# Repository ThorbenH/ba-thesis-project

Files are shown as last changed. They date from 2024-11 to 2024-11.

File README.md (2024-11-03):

# BarbelMotionTracker

This git project is dedicated to a prototype implementation that attempts to track and evaluate the motion of a barbell in the gym.

## 3D-Files

Here you will find the FFF (FDM) printable files for a case for the board. All STL-files are in metric (mm). To complete the assembly you will need some additional hardware (M3 screws, rubber pad, M3 heat set inserts, 4mmx0.5mm brass tubing, 2cm wide velcro strap)

## PCB_Design

Here you will find the KiCad8.0 design files as well as the pre exported gerbers (ready to order at JLCPCB). You will also find the ibom.html file which is a Interactive Bill Of Materials that you can open in any modern browser. It is of great use when doing board smd assembly.

## Software_Device

Here you will find a PlatformIO project that contains the software running on the board. It is written in C/C++ for the esp32 platform using the arduino framework.

To get started install VSCode, install the PlatformIO extension, plug in the board using the USB-C shared power and data port and make sure the board is turned on using the power switch.p

The software collects all the raw sensor data into a CSV-File for future of board processing.

Calibration modes can be selected by uncommenting preprocessor arguments in the "platformio.ini" file.

### Micro SD-Card

The sd-card has to be formatted as FAT32. FAT32 is only supported by micro-sd-cards with capacity less than 32GB.
The sd-card has to contain a settings.txt file that has to be populated. Check the "sdcard.h" code for details.
A good starting point might be this (make sure to include the empty lines at the end of the file, as the device expects these to write the BNO055 calibration to):

```
User
1
s
90.00
2.50
45.00
2.50
12.50
2.50
95.00
2.50

```

## Plot_Calibration

Contains a the python code to visualize a calibration as gathered by the device (see Software_Device).
To get the calibration matrix you can use the tool Magneto v1.2 at https://sites.google.com/view/sailboatinstruments1 .

## Post_Process_Data

First run "apply_calibration_and_split.py" to split one recording session into exercises and sets and apply the calibration. This requires a recorded session and a "cal_matrix.json" file in the subfolder "data". Make sure to set the correct file name for your recordig in "apply_calibration_and_split.py".
Next you can run "compute_orientation_and_motion.py". Make sure to set the correct target folder.

Some settings are required for these two steps. They can be set in "processing_settings.py".

All other files should contain "_thesis" in their name and where only used to create plots of the data for the thesis. Feel free to disregard these.

## Machine_Learning
To run the machine learning code you first need to create the dataset used for training and testing. The python code file "prepData.py" uses a hard coded location for the data. To generate the data required first run the Post_Process_Data pipeline. Then you can run the training in order "prepData.py" -> "train.py" -> "test.py".

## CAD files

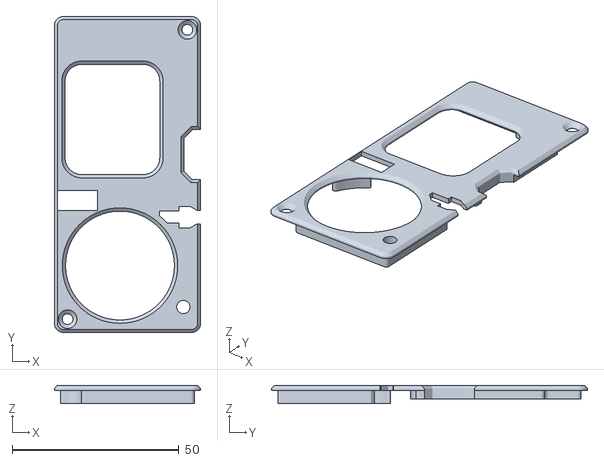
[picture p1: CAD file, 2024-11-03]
3D-Files/Lid.stl
43.9 x 94.7 x 5.40

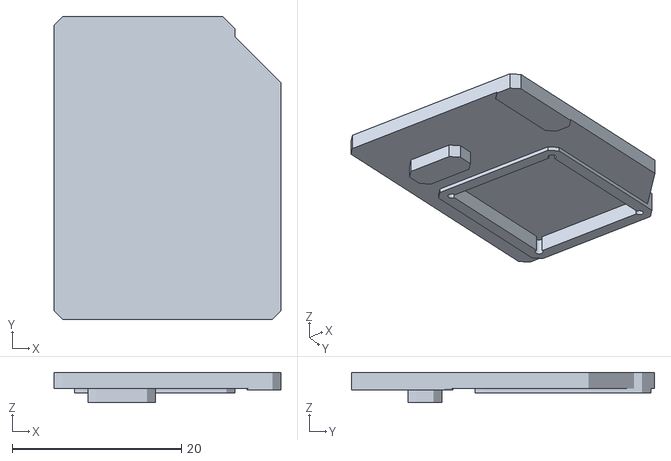
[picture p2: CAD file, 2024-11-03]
3D-Files/ScreenBackSupport.stl
26.8 x 35.8 x 3.55

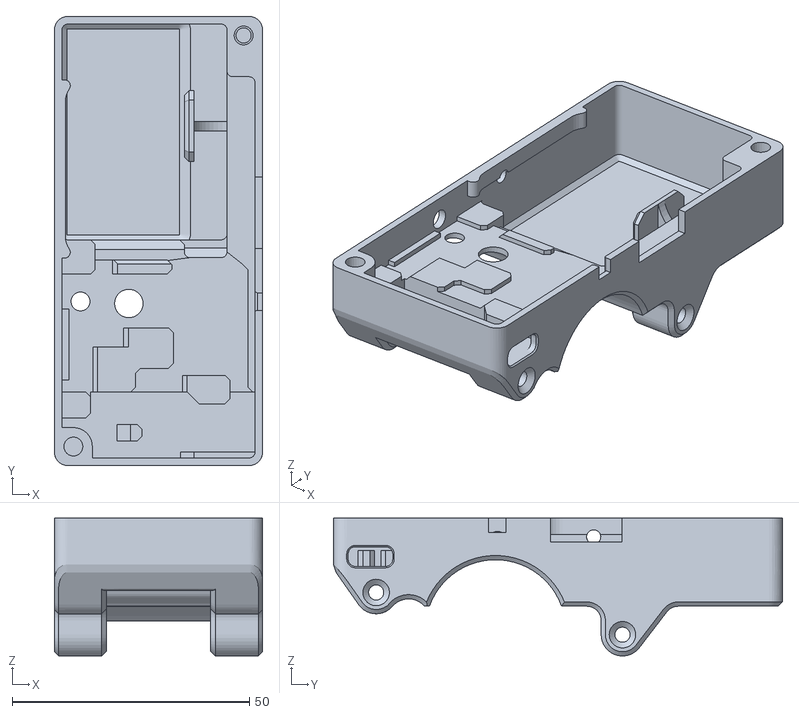
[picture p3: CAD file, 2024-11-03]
3D-Files/Case.stl
43.9 x 94.7 x 29.1

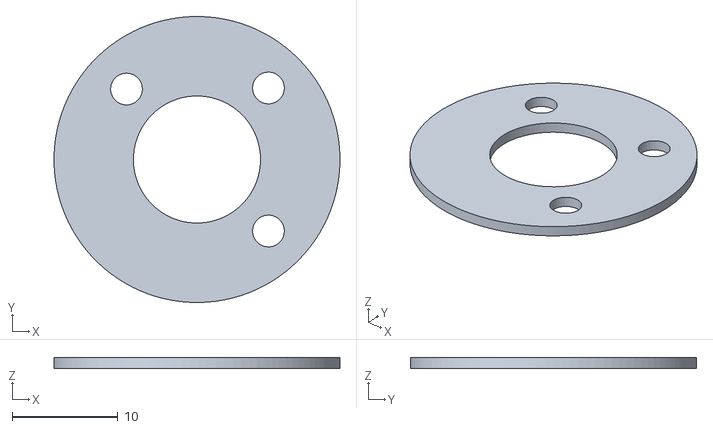
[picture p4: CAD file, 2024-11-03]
3D-Files/EncoderSpacer.stl
27.0 x 27.0 x 1.00

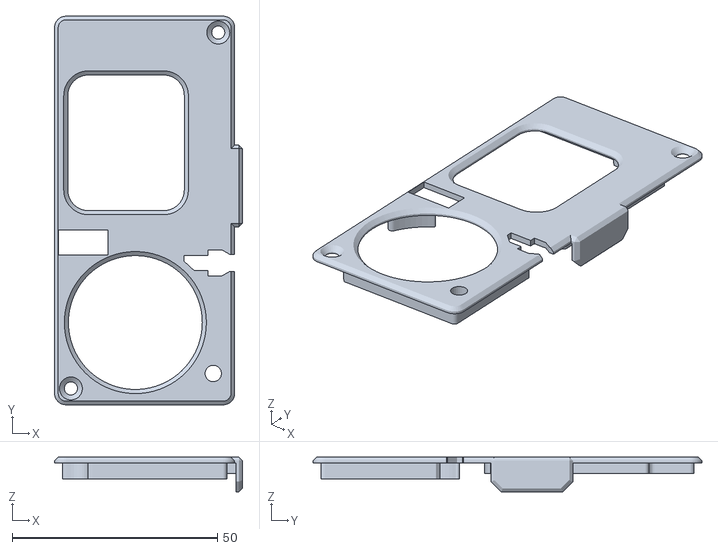
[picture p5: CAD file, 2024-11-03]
3D-Files/LidClosedSD.stl
45.8 x 94.7 x 8.50

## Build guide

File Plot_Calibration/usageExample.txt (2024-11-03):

18.92700	34.72900	-2.31934	
19.04907	34.93652	-1.98975	
19.01245	34.74731	-2.24609	
18.95142	34.85107	-1.94092	
19.01245	34.98535	-1.89209	
19.01245	34.98535	-1.89209	
19.13452	34.91211	-2.33154	
18.93921	34.80225	-2.27051	
19.05518	34.85107	-2.13623	
18.97583	34.91821	-2.27661	
18.97583	34.91821	-2.27661	
19.00024	34.84497	-2.34375	
19.06738	34.73511	-2.32544	
19.06738	34.73511	-2.32544	
18.90869	34.82056	-2.19727	
18.87817	35.02197	-2.22168	
18.91479	34.96094	-2.07520	
18.91479	34.96094	-2.07520	
19.01245	35.02808	-2.13013	
18.87817	34.80225	-2.25220	
18.90869	34.93042	-2.14844	
18.99414	35.05859	-2.15454	
18.99414	35.05859	-2.15454	
18.86597	35.19287	-2.17285	
19.00635	35.04028	-2.03247	
19.00635	35.04028	-2.03247	
19.14062	35.11963	-2.08740	
18.93311	35.09521	-2.27051	
19.03687	35.02197	-1.98975	
18.90869	35.09521	-1.98975	
18.90869	35.09521	-1.98975	
18.84155	35.29053	-1.64795	
19.02466	35.24170	-2.05688	
19.02466	35.24170	-2.05688	
19.17114	35.27222	-1.96533	
19.33594	35.32104	-1.97754	
19.17725	35.24780	-1.89819	
19.17114	35.24170	-1.90430	
19.17114	35.24170	-1.90430	
19.25659	35.51636	-2.06299	
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

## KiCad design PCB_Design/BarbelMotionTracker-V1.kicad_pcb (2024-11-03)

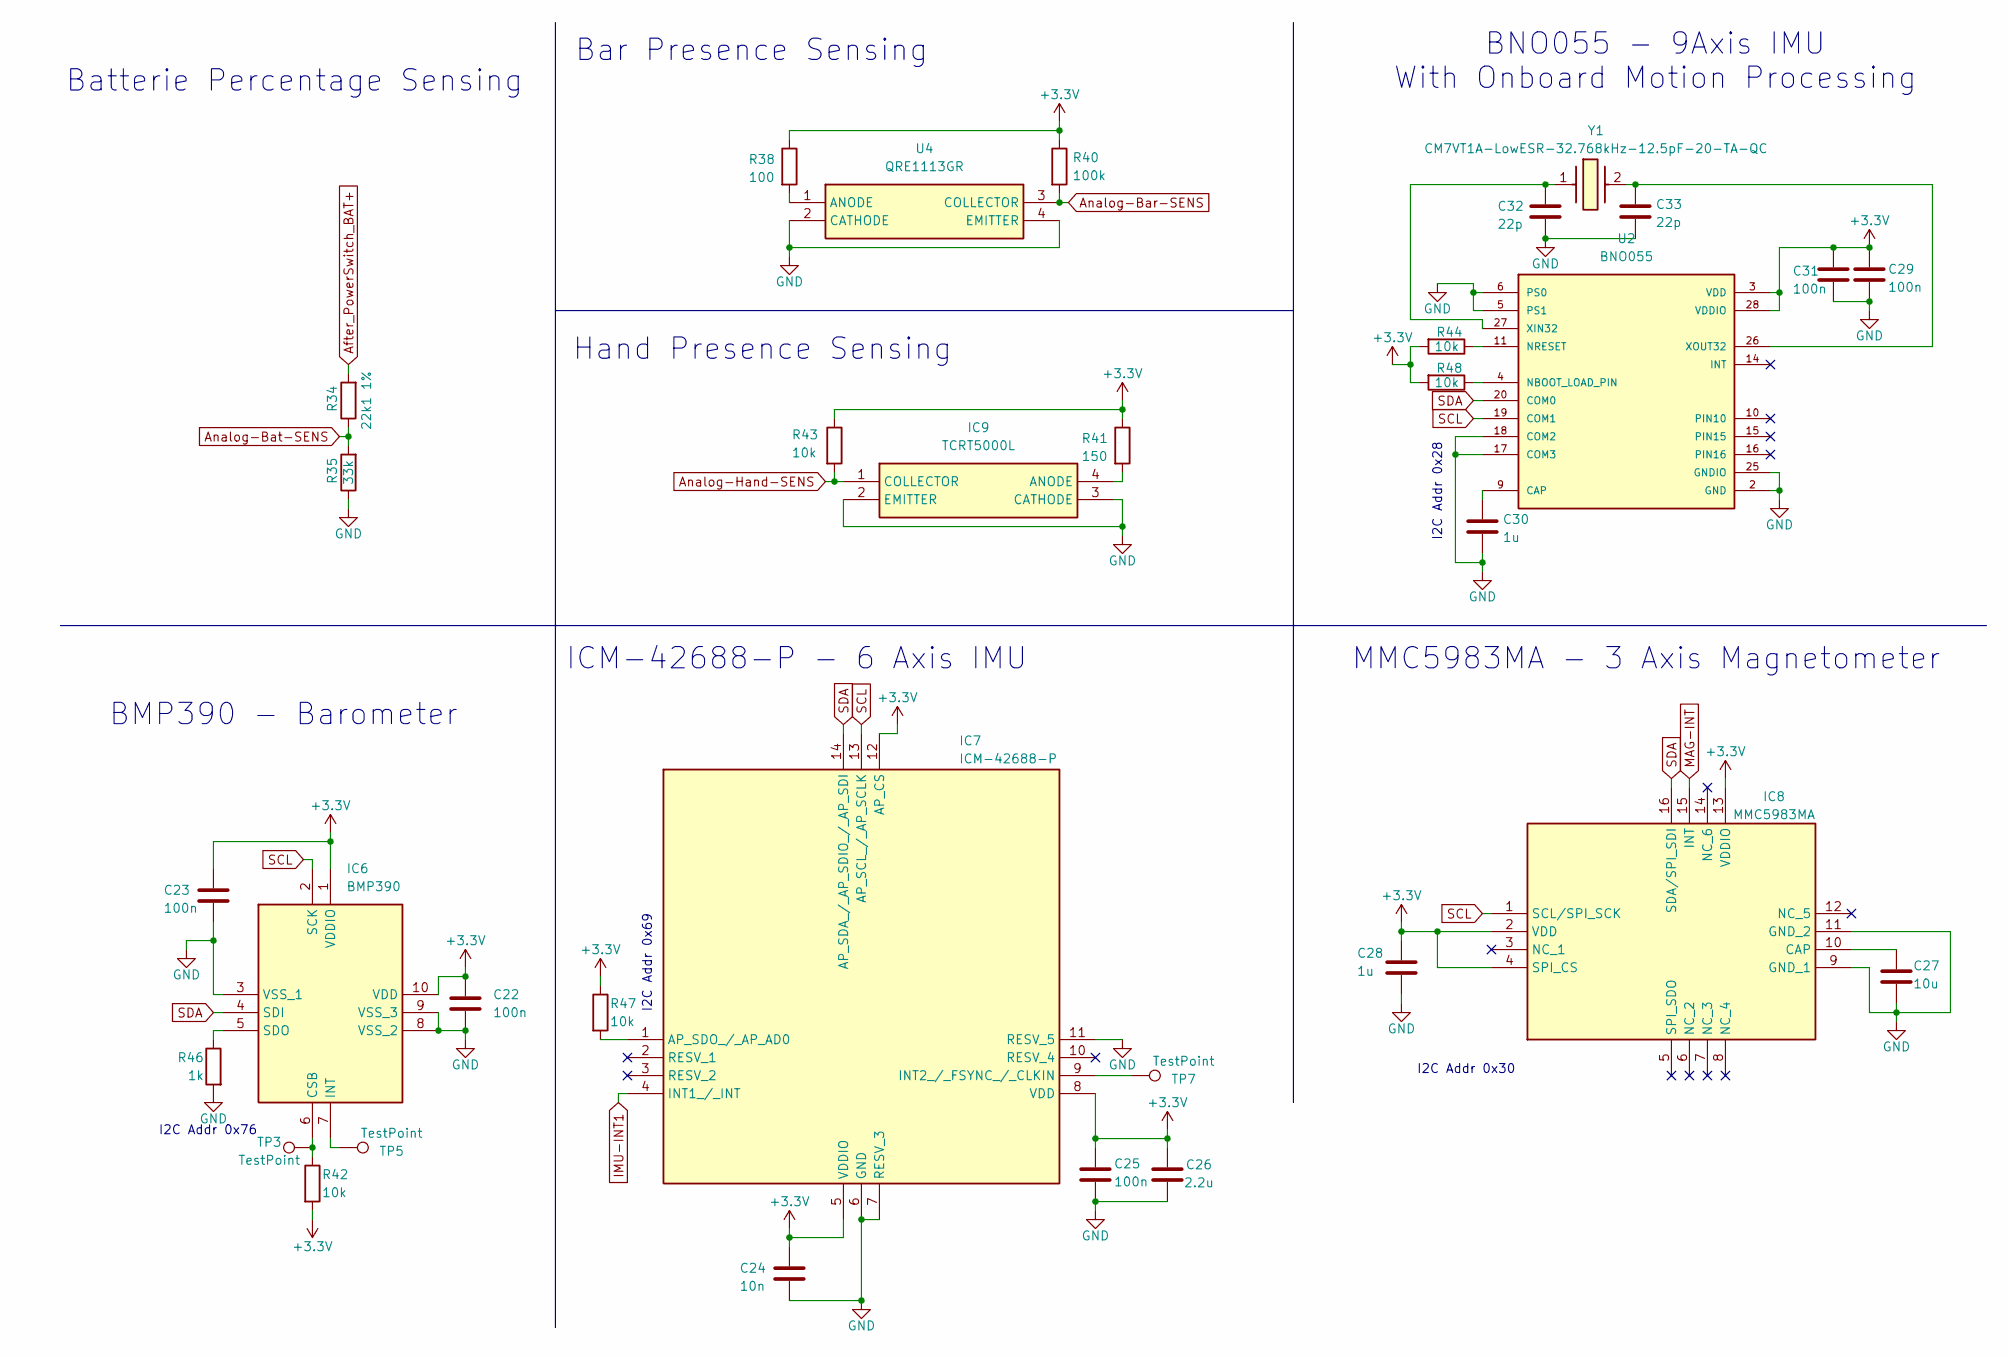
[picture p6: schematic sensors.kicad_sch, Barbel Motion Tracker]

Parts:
C22, C23, C25, C29, C31: 100n; C_0603_1608Metric
C24: 10n; C_0603_1608Metric
C26: 2.2u; C_0603_1608Metric
C27: 10u; C_0805_2012Metric
C28, C30: 1u; C_0603_1608Metric
C32, C33: 22p; C_0402_1005Metric
IC6: BMP390; Mouser Part Number 262-BMP390
IC7: ICM-42688-P; IIM42352; Mouser Part Number 410-ICM-42688-P
IC8: MMC5983MA; Mouser Part Number 438-MMC5983MA
IC9: TCRT5000L; Mouser Part Number 782-TCRT5000L
R34: 22k1 1%; R_0603_1608Metric
R35: 33k; R_0603_1608Metric
R38: 100; R_1206_3216Metric
R40: 100k; R_0603_1608Metric
R41: 150; R_1206_3216Metric
R42, R43, R44, R47, R48: 10k; R_0603_1608Metric
R46: 1k; R_0603_1608Metric
TP3, TP5, TP7: TestPoint; TestPoint_Pad_D1.0mm
U2: BNO055; LGA28R50P4X10_380X520X100
U4: QRE1113GR; Mouser Part Number 512-QRE1113GR
Y1: CM7VT1A-LowESR-32.768kHz-12.5pF-20-TA-QC; CM7V32768TBQA020; Mouser Part Number 428-202740-MG01

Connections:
+3.3V: C22.1, C23.1, C24.1, C25.1, C26.1, C28.1, C29.1, C31.1, IC6.1 (VDDIO), IC6.10 (VDD), IC7.5 (VDDIO), IC7.8 (VDD), IC7.12 (AP_CS), IC8.2 (VDD), IC8.4 (SPI_CS), IC8.13 (VDDIO), R38.1, R40.1, R41.1, R42.2, R43.1, R44.2, R47.1, R48.2, U2.3 (VDD), U2.28 (VDDIO); also elsewhere on the board
After_PowerSwitch_BAT+: R34.2; also elsewhere on the board
Analog-Bar-SENS: R40.2, U4.3 (COLLECTOR); also elsewhere on the board
Analog-Bat-SENS: R34.1, R35.2; also elsewhere on the board
Analog-Hand-SENS: IC9.1 (COLLECTOR), R43.2; also elsewhere on the board
GND: C22.2, C23.2, C24.2, C25.2, C26.2, C27.2, C28.2, C29.2, C30.2, C31.2, C32.2, C33.2, IC6.3 (VSS_1), IC6.8 (VSS_2), IC6.9 (VSS_3), IC7.6 (GND), IC7.7 (RESV_3), IC7.11 (RESV_5), IC8.9 (GND_1), IC8.11 (GND_2), IC9.2 (EMITTER), IC9.3 (CATHODE), R35.1, R46.2, U2.2 (GND), U2.5 (PS1), U2.6 (PS0), U2.17 (COM3), U2.18 (COM2), U2.25 (GNDIO), U4.2 (CATHODE), U4.4 (EMITTER); also elsewhere on the board
IMU-INT1: IC7.4 (INT1_/_INT); also elsewhere on the board
MAG-INT: IC8.15 (INT); also elsewhere on the board
unnamed: IC6.6 (CSB), R42.1, TP3.1
unnamed: IC6.7 (INT), TP5.1
unnamed: IC6.5 (SDO), R46.1
unnamed: IC7.1 (AP_SDO_/_AP_AD0), R47.2
unnamed: IC7.9 (INT2_/_FSYNC_/_CLKIN), TP7.1
unnamed: C27.1, IC8.10 (CAP)
unnamed: IC9.4 (ANODE), R41.2
unnamed: C30.1, U2.9 (CAP)
unnamed: R48.1, U2.4 (NBOOT_LOAD_PIN)
unnamed: R44.1, U2.11 (NRESET)
unnamed: C32.1, U2.27 (XIN32), Y1.1
unnamed: C33.1, U2.26 (XOUT32), Y1.2
unnamed: R38.2, U4.1 (ANODE)
SCL: IC6.2 (SCK), IC7.13 (AP_SCL_/_AP_SCLK), IC8.1 (SCL/SPI_SCK), U2.19 (COM1); also elsewhere on the board
SDA: IC6.4 (SDI), IC7.14 (AP_SDA_/_AP_SDIO_/_AP_SDI), IC8.16 (SDA/SPI_SDI), U2.20 (COM0); also elsewhere on the board

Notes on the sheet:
BMP390 - Barometer
I2C Addr 0x28
Batterie Percentage Sensing
ICM-42688-P - 6 Axis IMU
BNO055 - 9Axis IMU With Onboard Motion Processing
MMC5983MA - 3 Axis Magnetometer
Hand Presence Sensing
I2C Addr 0x69
I2C Addr 0x76
Bar Presence Sensing
I2C Addr 0x30

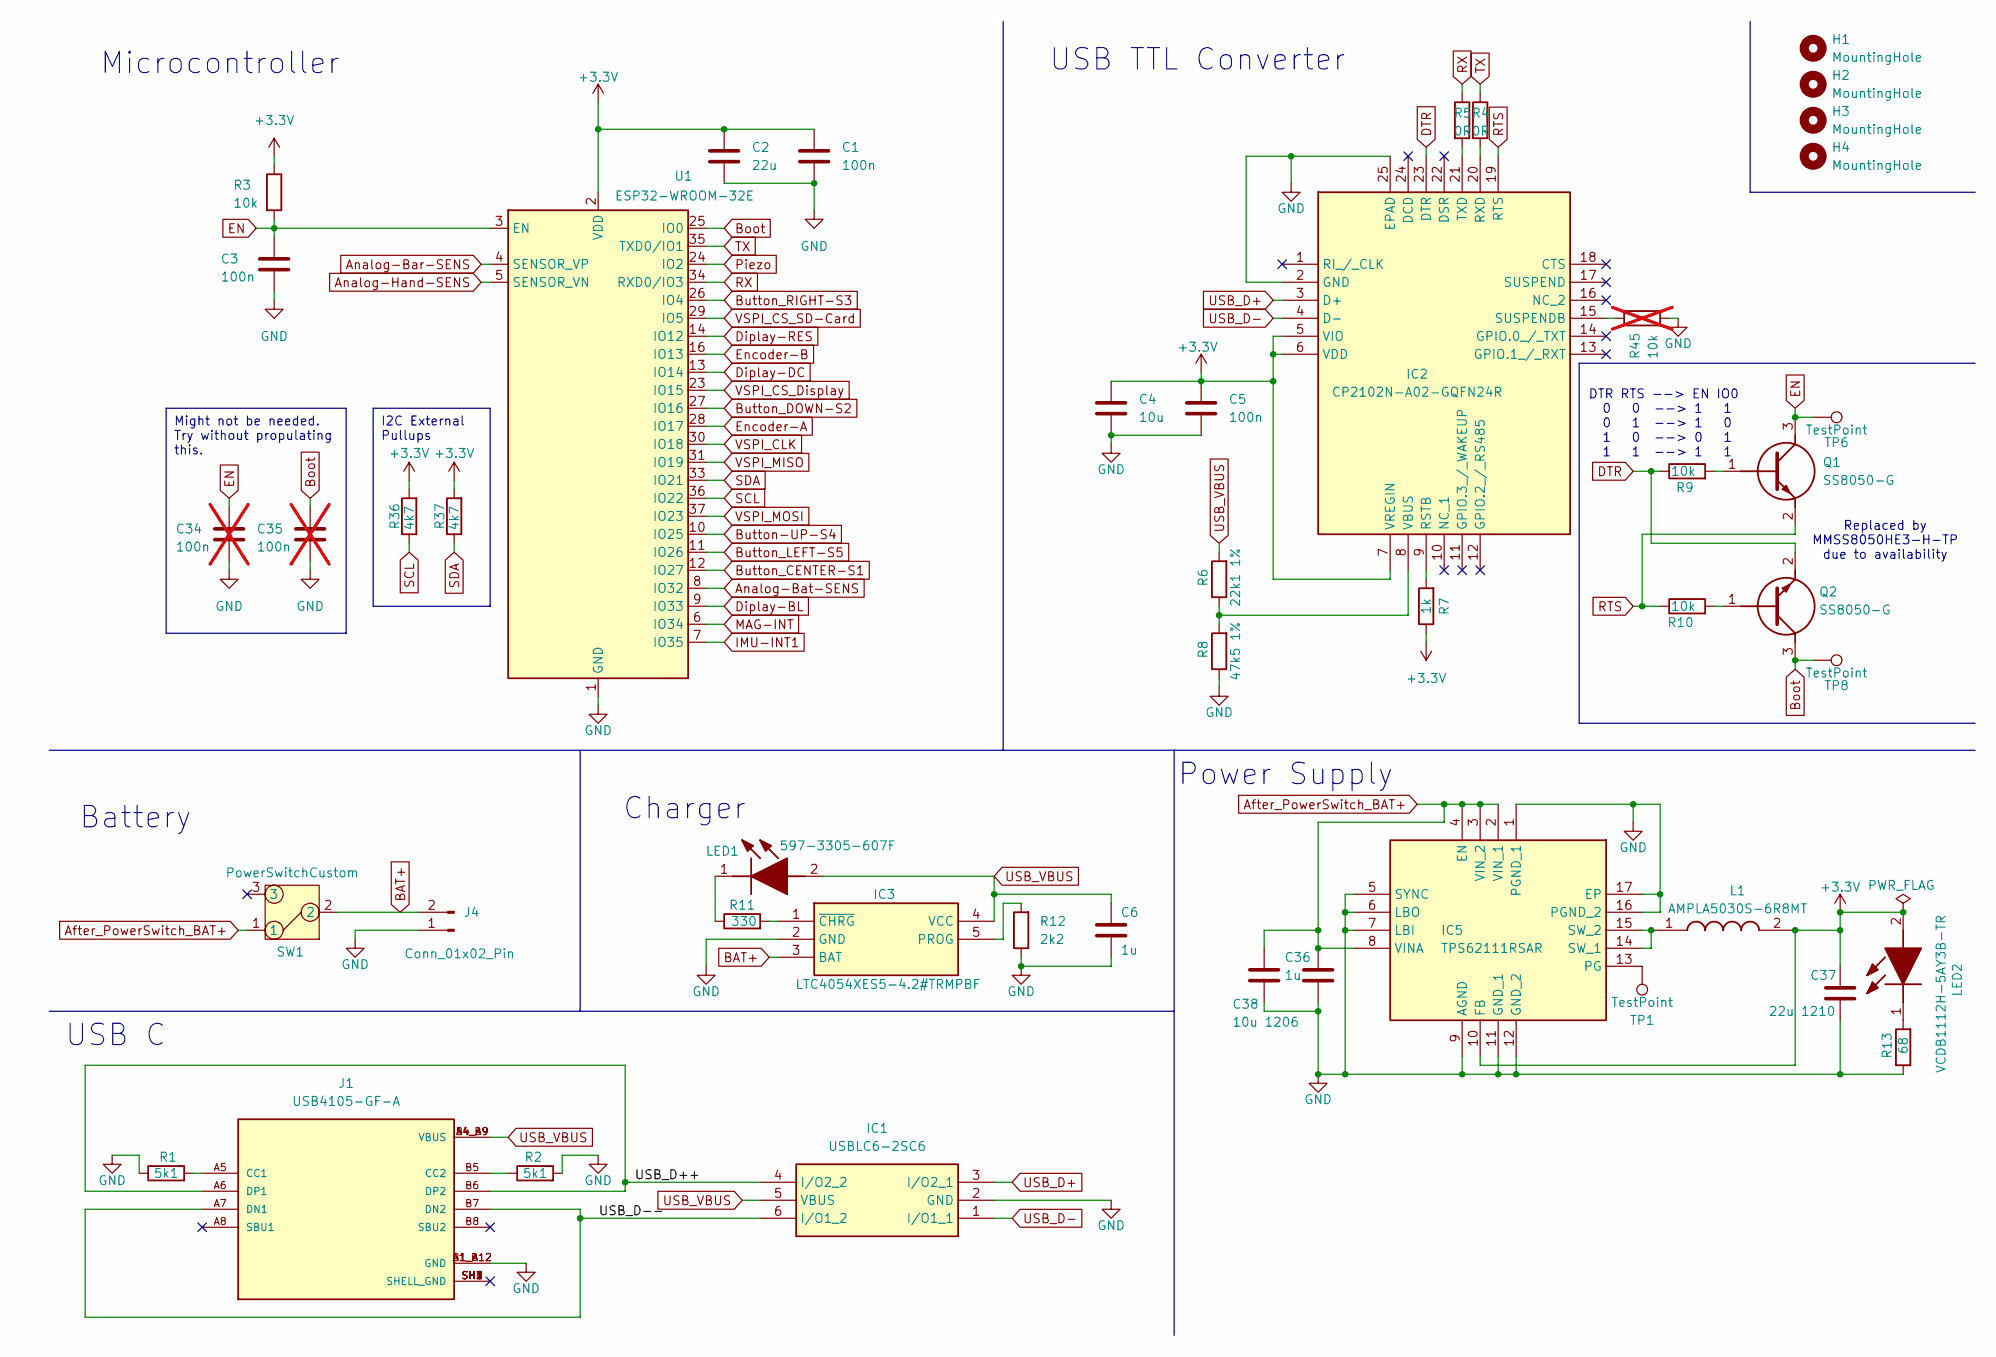
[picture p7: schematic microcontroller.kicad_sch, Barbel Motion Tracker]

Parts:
C1, C3, C5: 100n; C_0603_1608Metric
C2: 22u; C_0805_2012Metric
C4: 10u; C_0805_2012Metric
C6, C36: 1u; C_0603_1608Metric
C34, C35: 100n; C_0603_1608Metric; not fitted
C37: 22u 1210; C_1210_3225Metric
C38: 10u 1206; C_1206_3216Metric
H1, H2, H3, H4: MountingHole; MountingHole_2.2mm_M2
IC1: USBLC6-2SC6; SOT95P280X145-6N; Mouser Part Number 511-USBLC6-2SC6
IC2: CP2102N-A02-GQFN24R; QFN50P400X400X80-25N-D; Mouser Part Number 634-CP2102NA02QFN24R
IC3: LTC4054XES5-4.2#TRMPBF; SOT95P280X100-5N; Mouser Part Number 584-C4054XES54.2TMPF
IC5: TPS62111RSAR; QFN65P400X400X100-17N; Mouser Part Number 595-TPS62111RSAR
J1: USB4105-GF-A; GCT_USB4105-GF-A; PARTREV B3
J4: Conn_01x02_Pin; JST_PH_S2B-PH-K_1x02_P2.00mm_Horizontal
L1: AMPLA5030S-6R8MT; INDPM5752X300N; Manufacturer_Part_Number AMPLA5030S-6R8MT
LED1: 597-3305-607F; LEDC2012X70N; Mouser Part Number 645-597-3305-607F
LED2: VCDB1112H-5AY3B-TR; LEDC2012X90N; Mouser Part Number 327-VCDB1112H5AY3BTR
Q1, Q2: SS8050-G; SOT95P240X115-3N; Mouser Part Number 750-SS8050-G
R1, R2: 5k1; R_0603_1608Metric
R3, R9, R10: 10k; R_0603_1608Metric
R4, R5: 0R; R_0603_1608Metric
R6: 22k1 1%; R_0603_1608Metric
R7: 1k; R_0603_1608Metric
R8: 47k5 1%; R_0603_1608Metric
R11: 330; R_0603_1608Metric
R12: 2k2; R_0603_1608Metric
R13: 68; R_0603_1608Metric
R36, R37: 4k7; R_0603_1608Metric
R45: 10k; R_0603_1608Metric; not fitted
SW1: PowerSwitchCustom
TP1, TP6, TP8: TestPoint; TestPoint_Pad_D1.0mm
U1: ESP32-WROOM-32E

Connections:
+3.3V: C1.1, C2.1, C4.1, C5.1, C37.1, IC2.5 (VIO), IC2.6 (VDD), IC2.7 (VREGIN), IC5.10 (FB), L1.2, LED2.2 (A), R3.1, R7.1, R36.2, R37.2, U1.2 (VDD); also elsewhere on the board
/microcontroller/USB_D++: IC1.4 (I/O2_2), J1.A6 (DP1), J1.B6 (DP2)
/microcontroller/USB_D--: IC1.6 (I/O1_2), J1.A7 (DN1), J1.B7 (DN2)
After_PowerSwitch_BAT+: C36.1, C38.1, IC5.2 (VIN_1), IC5.3 (VIN_2), IC5.4 (EN), IC5.8 (VINA), SW1.1; also elsewhere on the board
Analog-Bar-SENS: U1.4 (SENSOR_VP); also elsewhere on the board
Analog-Bat-SENS: U1.8 (IO32); also elsewhere on the board
Analog-Hand-SENS: U1.5 (SENSOR_VN); also elsewhere on the board
BAT+: IC3.3 (BAT), J4.2, SW1.2
Boot: C35.1, Q2.3 (C), TP8.1, U1.25 (IO0)
Button-UP-S4: U1.10 (IO25); also elsewhere on the board
Button_CENTER-S1: U1.12 (IO27); also elsewhere on the board
Button_DOWN-S2: U1.27 (IO16); also elsewhere on the board
Button_LEFT-S5: U1.11 (IO26); also elsewhere on the board
Button_RIGHT-S3: U1.26 (IO4); also elsewhere on the board
DTR: IC2.23 (DTR), Q2.2 (E), R9.1
Diplay-BL: U1.9 (IO33); also elsewhere on the board
Diplay-DC: U1.13 (IO14); also elsewhere on the board
Diplay-RES: U1.14 (IO12); also elsewhere on the board
EN: C3.1, C34.1, Q1.3 (C), R3.2, TP6.1, U1.3 (EN)
Encoder-A: U1.28 (IO17); also elsewhere on the board
Encoder-B: U1.16 (IO13); also elsewhere on the board
GND: C1.2, C2.2, C3.2, C4.2, C5.2, C6.2, C34.2, C35.2, C36.2, C37.2, C38.2, IC1.2 (GND), IC2.2 (GND), IC2.25 (EPAD), IC3.2 (GND), IC5.1 (PGND_1), IC5.5 (SYNC), IC5.6 (LBO), IC5.7 (LBI), IC5.9 (AGND), IC5.11 (GND_1), IC5.12 (GND_2), IC5.16 (PGND_2), IC5.17 (EP), J1.A1_B12 (GND), J1.B1_A12 (GND), J4.1, R1.1, R2.2, R8.1, R12.1, R13.1, R45.2, U1.1 (GND), U1.15 (GND), U1.38 (GND), U1.39 (GND); also elsewhere on the board
IMU-INT1: U1.7 (IO35); also elsewhere on the board
MAG-INT: U1.6 (IO34); also elsewhere on the board
unnamed: IC2.9 (RSTB), R7.2
unnamed: IC2.20 (RXD), R4.2
unnamed: IC2.15 (SUSPENDB), R45.1
unnamed: IC2.21 (TXD), R5.2
unnamed: IC2.8 (VBUS), R6.1, R8.2
unnamed: IC3.5 (PROG), R12.2
unnamed: IC3.1 (~CHRG), R11.2
unnamed: IC5.13 (PG), TP1.1
unnamed: IC5.14 (SW_1), IC5.15 (SW_2), L1.1
unnamed: J1.A5 (CC1), R1.2
unnamed: J1.B5 (CC2), R2.1
unnamed: LED1.1 (K), R11.1
unnamed: LED2.1 (K), R13.2
unnamed: Q1.1 (B), R9.2
unnamed: Q2.1 (B), R10.2
Piezo: U1.24 (IO2); also elsewhere on the board
RTS: IC2.19 (RTS), Q1.2 (E), R10.1
RX: R5.1, U1.34 (RXD0/IO3)
SCL: R36.1, U1.36 (IO22); also elsewhere on the board
SDA: R37.1, U1.33 (IO21); also elsewhere on the board
TX: R4.1, U1.35 (TXD0/IO1)
USB_D+: IC1.3 (I/O2_1), IC2.3 (D+)
USB_D-: IC1.1 (I/O1_1), IC2.4 (D-)
USB_VBUS: C6.1, IC1.5 (VBUS), IC3.4 (VCC), J1.A4_B9 (VBUS), J1.B4_A9 (VBUS), LED1.2 (A), R6.2
VSPI_CLK: U1.30 (IO18); also elsewhere on the board
VSPI_CS_Display: U1.23 (IO15); also elsewhere on the board
VSPI_CS_SD-Card: U1.29 (IO5); also elsewhere on the board
VSPI_MISO: U1.31 (IO19); also elsewhere on the board
VSPI_MOSI: U1.37 (IO23); also elsewhere on the board

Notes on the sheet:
I2C External Pullups
Might not be needed. Try without propulating this.
DTR RTS --> EN IO0 0 0 --> 1 1 0 1 --> 1 0 1 0 --> 0 1 1 1 --> 1 1
USB C
Charger
USB TTL Converter
Replaced by MMSS8050HE3-H-TP due to availability
Battery
Microcontroller
Power Supply

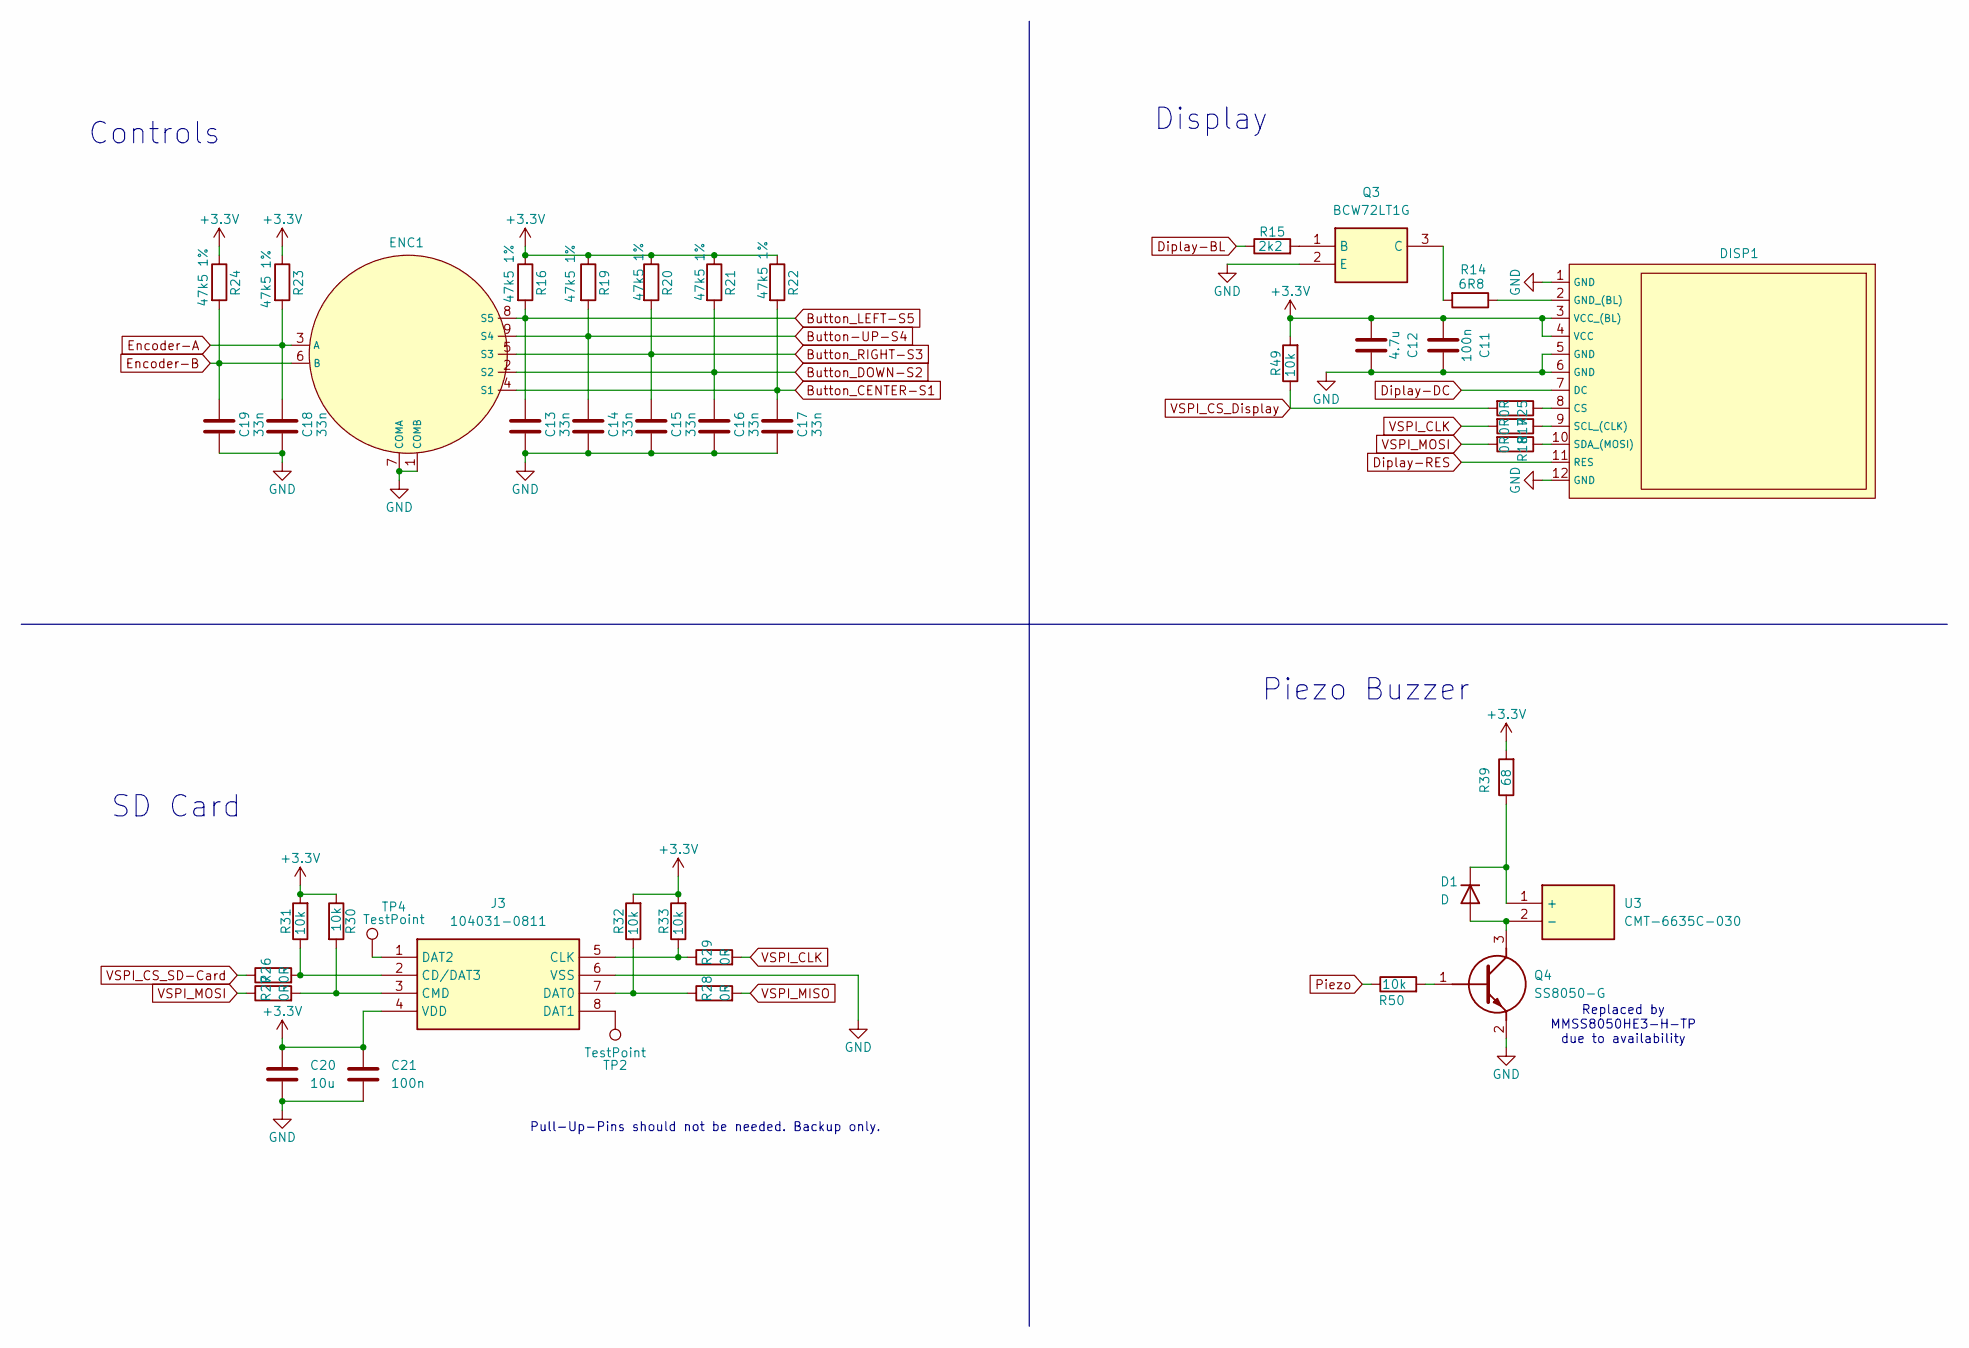
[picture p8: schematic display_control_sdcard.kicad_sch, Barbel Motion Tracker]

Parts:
C11, C21: 100n; C_0603_1608Metric
C12: 4.7u; C_0603_1608Metric
C13, C14, C15, C16, C17, C18, C19: 33n; C_0603_1608Metric
C20: 10u; C_0805_2012Metric
D1: D; D_0805_2012Metric
DISP1: Display_ST7789V2
ENC1: ZippyRotaryEncoder_ANO
J3: 104031-0811; 1040310811; Mouser Part Number 538-104031-0811
Q3: BCW72LT1G; SOT96P237X111-3N; Mouser Part Number 863-BCW72LT1G
Q4: SS8050-G; SOT95P240X115-3N; Mouser Part Number 750-SS8050-G
R14: 6R8; R_1206_3216Metric
R15: 2k2; R_0603_1608Metric
R16, R19, R20, R21, R22, R23, R24: 47k5 1%; R_0603_1608Metric
R17, R18, R25, R26, R27, R28, R29: 0R; R_0603_1608Metric
R30, R31, R32, R33, R49, R50: 10k; R_0603_1608Metric
R39: 68; R_0603_1608Metric
TP2, TP4: TestPoint; TestPoint_Pad_D1.0mm
U3: CMT-6635C-030; CMT6635C030; Mouser Part Number 490-CMT-6635C-030

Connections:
+3.3V: C11.1, C12.1, C20.1, C21.1, DISP1.3 (VCC_(BL)), DISP1.4 (VCC), J3.4 (VDD), R16.1, R19.1, R20.1, R21.1, R22.1, R23.1, R24.1, R30.1, R31.2, R32.2, R33.2, R39.2, R49.2; also elsewhere on the board
Button-UP-S4: C14.2, ENC1.9 (S4), R19.2; also elsewhere on the board
Button_CENTER-S1: C17.2, ENC1.4 (S1), R22.2; also elsewhere on the board
Button_DOWN-S2: C16.2, ENC1.2 (S2), R21.2; also elsewhere on the board
Button_LEFT-S5: C13.2, ENC1.8 (S5), R16.2; also elsewhere on the board
Button_RIGHT-S3: C15.2, ENC1.5 (S3), R20.2; also elsewhere on the board
Diplay-BL: R15.1; also elsewhere on the board
Diplay-DC: DISP1.7 (DC); also elsewhere on the board
Diplay-RES: DISP1.11 (RES); also elsewhere on the board
Encoder-A: C18.2, ENC1.3 (A), R23.2; also elsewhere on the board
Encoder-B: C19.2, ENC1.6 (B), R24.2; also elsewhere on the board
GND: C11.2, C12.2, C13.1, C14.1, C15.1, C16.1, C17.1, C18.1, C19.1, C20.2, C21.2, DISP1.1 (GND), DISP1.5 (GND), DISP1.6 (GND), DISP1.12 (GND), ENC1.1 (COMB), ENC1.7 (COMA), J3.6 (VSS), Q3.2 (E), Q4.2 (E); also elsewhere on the board
unnamed: D1.2 (A), Q4.3 (C), U3.2 (-)
unnamed: D1.1 (K), R39.1, U3.1 (+)
unnamed: DISP1.8 (CS), R25.1
unnamed: DISP1.2 (GND_(BL)), R14.1
unnamed: DISP1.9 (SCL_(CLK)), R17.1
unnamed: DISP1.10 (SDA_(MOSI)), R18.1
unnamed: J3.2 (CD/DAT3), R26.2, R31.1
unnamed: J3.5 (CLK), R29.1, R33.1
unnamed: J3.3 (CMD), R27.2, R30.2
unnamed: J3.7 (DAT0), R28.1, R32.1
unnamed: J3.8 (DAT1), TP2.1
unnamed: J3.1 (DAT2), TP4.1
unnamed: Q3.1 (B), R15.2
unnamed: Q3.3 (C), R14.2
unnamed: Q4.1 (B), R50.2
Piezo: R50.1; also elsewhere on the board
VSPI_CLK: R17.2, R29.2; also elsewhere on the board
VSPI_CS_Display: R25.2, R49.1; also elsewhere on the board
VSPI_CS_SD-Card: R26.1; also elsewhere on the board
VSPI_MISO: R28.2; also elsewhere on the board
VSPI_MOSI: R18.2, R27.1; also elsewhere on the board

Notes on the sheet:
Pull-Up-Pins should not be needed. Backup only.
Piezo Buzzer
Display
Controls
SD Card
Replaced by MMSS8050HE3-H-TP due to availability

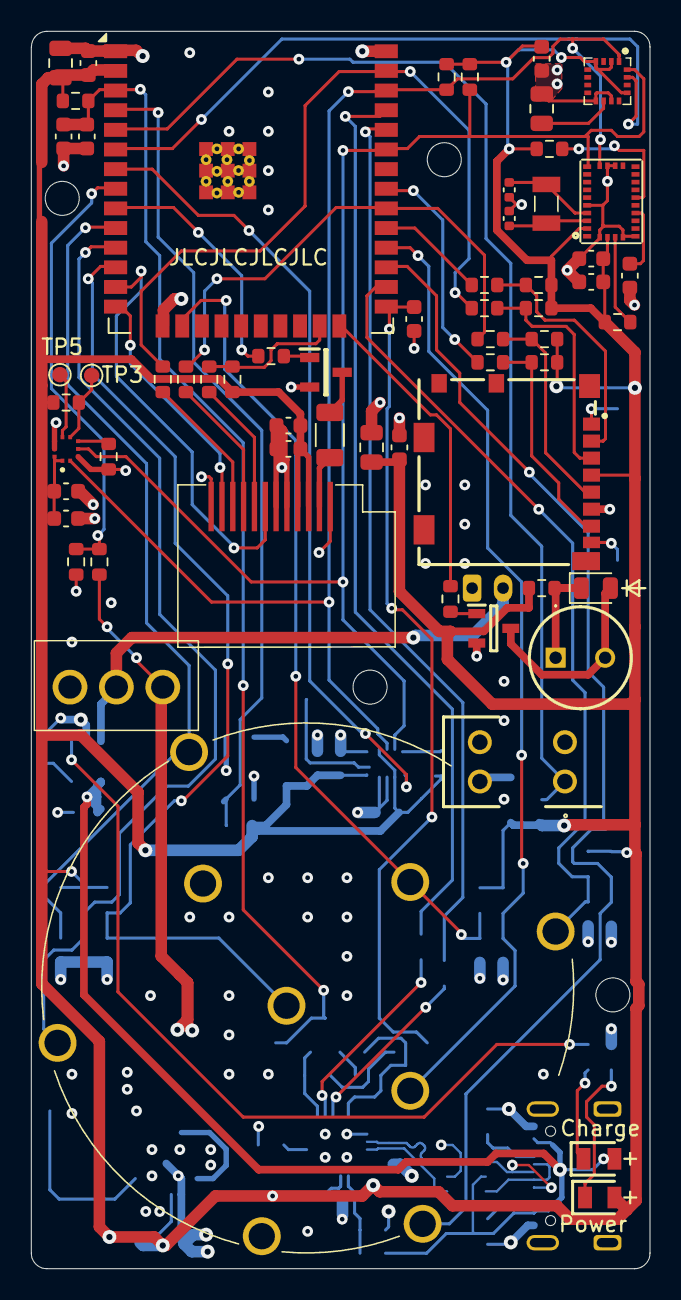
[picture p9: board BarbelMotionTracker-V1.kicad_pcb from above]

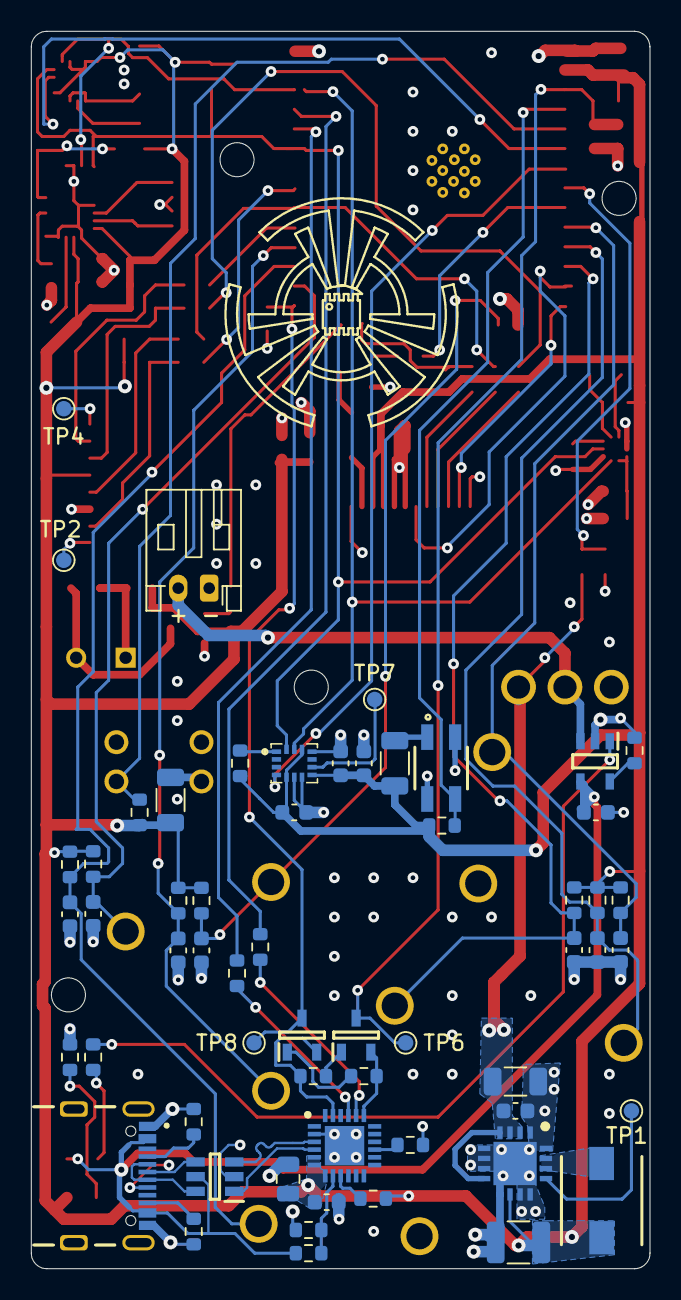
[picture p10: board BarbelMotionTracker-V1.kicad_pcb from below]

Board: 4 copper layers, 40.0 x 80.0 mm, 123 parts (58 on the bottom side), 81 nets.

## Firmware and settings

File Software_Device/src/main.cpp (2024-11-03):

#include <Arduino.h>
#include "pins.h"

#include "analogSensors.h"
#include "inputWheel.h"
#include "piezo.h"
#include "sdcard.h"
#include "display.h"
#include "bmp390.h"
#include "bno055.h"
#include "mmc5983ma.h"
#include "icm-42688-p.h"

static const int core_sd_card_io = 0; //PRO_CPU | wifi/bt core by default | has special watchdog if scheduler isn't triggered in long time -> resets microcontroler (so wireless is not stuck in loop)
static const int core_sensors    = 1; //APP_CPU | app core by default

static const int read_sensors_hardware_timer = 0; 
static const uint16_t freq_timer_divider = 80;      // Divide timer freq (80 MHz) by this -> new clock rate is 1mhz
static const uint64_t timer_count = 2000;               // Timer counts to this value
// freq_timer_divider and timer_count define sensor reading frequency -> 500Hz
static const int taskHandleIOYieldTime_ms = 5; //5ms are by far enough for the higher priority sd task to take over
static const int taskSDCardFreq = 10; //in Hz | approximate as the io task might hold the spi sem
static const int sensorReadingsQueueLen = 100; //number of elements

static const int delayBetweenSensorReads_us = 1000000/500; // 1m/500Hz
static const int bno055DelayBetweenReads_us = 1000000/100; // 1m/100Hz
static const int bmp390DelayBetweenReads_us = 1000000/25; // 1m/25Hz

static const float dataNotAvailable = -10000;//out of range for sensor reading -> must be only this


static const int encoderScaleDown = 2;


static hw_timer_t *hwTimerReadSensors = NULL;
static SemaphoreHandle_t semTimerReadSensors = NULL;

static SemaphoreHandle_t spiControlMutex;

static QueueHandle_t sensorReadingsQueue;

TaskHandle_t taskHandleReadSensors;
TaskHandle_t taskHandleHandleIO;
TaskHandle_t taskHandleSDCard;

struct Measurement_t {
  double lin_acc_x, lin_acc_y, lin_acc_z;                // BNO055               | linear acceleration, double [meters/second^2]
  double abs_quat_w, abs_quat_x, abs_quat_y, abs_quat_z; // BNO055               | absolute orientation, double [quaternion]
  float acc_x, acc_y, acc_z;                             // ICM 42688P           | acceleration, float  [meters/second^2]
  float rot_x, rot_y, rot_z;                             // ICM 42688P           | angular velocity, float [degrees/second]
  float temp;                                            // ICM 42688P not used  | temperature gyro die, float [Celsius]
  double mag_x, mag_y, mag_z;                            // MCC5983MA            | double [micro Tesla] (+/-800 uT)
  float abs_height;                                      // BMP390               | altitude, float [meters]
  int64_t time_since_last_measure_us;                    //                      | int [micro seconds]
};

void delayNonBlockingMillis(int millis){
    if(millis <=0){
        return;
    }
    vTaskDelay(millis / portTICK_PERIOD_MS);
}

void IRAM_ATTR hwTimerReadSensorsCallback(){
    BaseType_t task_woken = pdFALSE;
    xSemaphoreGiveFromISR(semTimerReadSensors, &task_woken);//useTaskNotify instead?
    if (task_woken) {
        portYIELD_FROM_ISR();
    }
}

int64_t lastMeasurementTime_us = esp_timer_get_time();
int64_t currentMeasurementTime_us = esp_timer_get_time();

int64_t lastMeasurementTimeBNO055_us = esp_timer_get_time();
int64_t lastMeasurementTimeBMP390_us = esp_timer_get_time();

Measurement_t readMesurement;
void taskReadSensors(TimerHandle_t xTimer){
    hwTimerReadSensors = timerBegin(read_sensors_hardware_timer, freq_timer_divider, true);//use esptimer instead?
    timerAttachInterrupt(hwTimerReadSensors, &hwTimerReadSensorsCallback, true);
    timerAlarmWrite(hwTimerReadSensors, timer_count, true);
    timerAlarmEnable(hwTimerReadSensors);

    lastMeasurementTimeBMP390_us = esp_timer_get_time()-bmp390DelayBetweenReads_us+delayBetweenSensorReads_us;//delay BMP390 first read so it does not occur concurrently with BNO055
    while(1) {
        if (xSemaphoreTake(semTimerReadSensors, portMAX_DELAY) == pdFALSE) {
            continue;
        }
        currentMeasurementTime_us = esp_timer_get_time();
        if(lastMeasurementTimeBNO055_us + bno055DelayBetweenReads_us <= currentMeasurementTime_us){//100Hz
            getDataBNO055(&(readMesurement.lin_acc_x), &(readMesurement.lin_acc_y), &(readMesurement.lin_acc_z),
                        &(readMesurement.abs_quat_w), &(readMesurement.abs_quat_x), &(readMesurement.abs_quat_y), &(readMesurement.abs_quat_z));
            lastMeasurementTimeBNO055_us = currentMeasurementTime_us;
        } else {
            readMesurement.lin_acc_x = dataNotAvailable;
            readMesurement.lin_acc_y = dataNotAvailable;
            readMesurement.lin_acc_z = dataNotAvailable;
            readMesurement.abs_quat_w = dataNotAvailable;
            readMesurement.abs_quat_x = dataNotAvailable;
            readMesurement.abs_quat_y = dataNotAvailable;
            readMesurement.abs_quat_z = dataNotAvailable;
        }

        
        getDataICM42688PA(&(readMesurement.acc_x), &(readMesurement.acc_y), &(readMesurement.acc_z),
            &(readMesurement.rot_x), &(readMesurement.rot_y), &(readMesurement.rot_z),
            &(readMesurement.temp));
        getDataMMC5983MA(&(readMesurement.mag_x), &(readMesurement.mag_y), &(readMesurement.mag_z));

        if(lastMeasurementTimeBMP390_us + bmp390DelayBetweenReads_us <= currentMeasurementTime_us){//25Hz
            getDataBMP390(&(readMesurement.abs_height));
            lastMeasurementTimeBMP390_us = currentMeasurementTime_us;
        } else {
            readMesurement.abs_height = dataNotAvailable;
        }

        readMesurement.time_since_last_measure_us = currentMeasurementTime_us-lastMeasurementTime_us;
        if (xQueueSend(sensorReadingsQueue, (void *)&readMesurement, portTICK_PERIOD_MS) == pdFALSE) {
            Serial.println("---------------------------------!!! Lost data !!!---------------------------------");
            continue;//queue was full and timeout from waiting... we have a big issue
        }
        lastMeasurementTime_us = currentMeasurementTime_us;
    }
}


float getWeight(Page page){
    switch (page)
    {
        case PAGE_BENCH:
            return setting_weight_bench;
        case PAGE_OVERHEAD:
            return setting_weight_overhead;
        case PAGE_CURL:
            return setting_weight_curl;
        case PAGE_SQUAT:
            return setting_weight_squat;
        default:
            return dataNotAvailable;
    }
}

float getWeightStepSize(Page page){
    switch (page)
    {
        case PAGE_BENCH:
            return setting_weight_bench_stepsize;
        case PAGE_OVERHEAD:
            return setting_weight_overhead_stepsize;
        case PAGE_CURL:
            return setting_weight_curl_stepsize;
        case PAGE_SQUAT:
            return setting_weight_squat_stepsize;
        default:
            return 0;
    }
}


void setWeight(Page page, float weight){//requires spiwrite -> make sure you have permission
    switch (page)
    {
        case PAGE_BENCH:
            setting_weight_bench = weight;
            break;
        case PAGE_OVERHEAD:
            setting_weight_overhead = weight;
            break;
        case PAGE_CURL:
            setting_weight_curl = weight;
            break;
        case PAGE_SQUAT:
            setting_weight_squat = weight;
            break;
        default:
            break;
    }
    writeSettingsToSDCard();
}

void moveRight(){
    switch (setting_current_page)
    {
        case PAGE_BENCH:
            setting_current_page = pageToChar(PAGE_OVERHEAD);
            break;
        case PAGE_OVERHEAD:
            setting_current_page = pageToChar(PAGE_CURL);
            break;
        case PAGE_CURL:
            setting_current_page = pageToChar(PAGE_SQUAT);
            break;
        case PAGE_SQUAT:
            setting_current_page = pageToChar(PAGE_USER);
            break;
        default:
            setting_current_page = pageToChar(PAGE_BENCH);
            break;
    }
    writeSettingsToSDCard();
}

void moveLeft(){
    switch (setting_current_page)
    {
        case PAGE_BENCH:
            setting_current_page = pageToChar(PAGE_USER);
            break;
        case PAGE_OVERHEAD:
            setting_current_page = pageToChar(PAGE_BENCH);
            break;
        case PAGE_CURL:
            setting_current_page = pageToChar(PAGE_OVERHEAD);
            break;
        case PAGE_SQUAT:
            setting_current_page = pageToChar(PAGE_CURL);
            break;
        default:
            setting_current_page = pageToChar(PAGE_SQUAT);
            break;
    }
    writeSettingsToSDCard();
}

void movePage(int left, int right){
    for(int i = 0; i<left; i++){
        moveLeft();
    }
    for(int i = 0; i<right; i++){
        moveRight();
    }
}

void taskHandleIO(TimerHandle_t xTimer){
    attachInputWheelInterrupts();
    if (xSemaphoreTake(spiControlMutex, portMAX_DELAY) == pdTRUE) {//display inital upon startup
        displayPage(charToPage(setting_current_page));
        updateBarPresent();
        updateHandPresent();
        updatePage(charToPage(setting_current_page), handPresent, barPresent, batteryVoltage, getWeight(charToPage(setting_current_page)), true);
        xSemaphoreGive(spiControlMutex);
    }
    while(1) {
        delayNonBlockingMillis(taskHandleIOYieldTime_ms);
        if (xSemaphoreTake(spiControlMutex, portMAX_DELAY) == pdFALSE) {
            continue;
        }
        updateBarPresent();
        updateHandPresent();
        //Serial.println("Screen update");
        if(button_right_presses-button_left_presses != 0){
            movePage(button_left_presses, button_right_presses);

            button_right_presses = 0;
            button_left_presses = 0;

            displayPage(charToPage(setting_current_page));
            updatePage(charToPage(setting_current_page), handPresent, barPresent, batteryVoltage, getWeight(charToPage(setting_current_page)), true);
        }
        if(abs(encoder) > encoderScaleDown){
            int change = (encoder/encoderScaleDown);
            float newWeight = getWeight(charToPage(setting_current_page)) + change*getWeightStepSize(charToPage(setting_current_page));
            
            encoder -= change*encoderScaleDown;
            
            setWeight(charToPage(setting_current_page), newWeight);
        }
        updatePage(charToPage(setting_current_page), handPresent, barPresent, batteryVoltage, getWeight(charToPage(setting_current_page)), false);
        xSemaphoreGive(spiControlMutex);
    }
}

int taskSDCardYieldCalc_ms(int timeTaken_us){
    int available_us = 1'000'000/taskSDCardFreq;
    int sleep_time_ms = (available_us-timeTaken_us)/1000;
    //Serial.print("Sleeping: ");
    //Serial.println(sleep_time_ms);
    if(sleep_time_ms<0){
        return 0;
    }
    return sleep_time_ms;
}

char doubleToStringBuffer[50];
String doubleToString(double value) {//uses 5 decimal places
    if(value==dataNotAvailable){
        return "x";
    }
    sprintf(doubleToStringBuffer, "%.5lf", value);
    return String(doubleToStringBuffer);
}

char floatToString2DecimalsBuffer[50];
String floatToString2Decimals(float value) {//uses 2 decimal places
    if(value==dataNotAvailable){
        return "x";
    }
    sprintf(floatToString2DecimalsBuffer, "%.2f", value);
    return String(floatToString2DecimalsBuffer);
}

Measurement_t writeMesurement;
void taskSDCard(TimerHandle_t xTimer){
    int64_t taskSDCardStartTime = esp_timer_get_time();
    int64_t stringDoneTime= esp_timer_get_time();
    int64_t taskDoneTime = esp_timer_get_time();
    while(1) {
        delayNonBlockingMillis(taskSDCardYieldCalc_ms(taskDoneTime-taskSDCardStartTime));
        if (xSemaphoreTake(spiControlMutex, portMAX_DELAY) == pdFALSE) {
            continue;
        }
        taskSDCardStartTime = esp_timer_get_time();
        updateBarPresent();
        updateHandPresent();
        updateBatteryVoltage();
        String text = "";
        int freeSpace = uxQueueSpacesAvailable(sensorReadingsQueue);
        while(xQueueReceive(sensorReadingsQueue, (void *)&writeMesurement, 0) == pdTRUE) {
            
            #if defined(CALIBRATE_ACCELEROMETER) && !defined(CALIBRATE_MAGNETOMETER) && !defined(CALIBRATE_GYROSCOPE)
            if(takeCalibrationMeasurement()){
                text += doubleToString(writeMesurement.acc_x); text += "\t";
                text += doubleToString(writeMesurement.acc_y); text += "\t";
                text += doubleToString(writeMesurement.acc_z); text += "\n";
            }
            #elif defined(CALIBRATE_MAGNETOMETER) && !defined(CALIBRATE_ACCELEROMETER) && !defined(CALIBRATE_GYROSCOPE)
            text += doubleToString(writeMesurement.mag_x); text += "\t";
            text += doubleToString(writeMesurement.mag_y); text += "\t";
            text += doubleToString(writeMesurement.mag_z); text += "\n";
            #elif defined(CALIBRATE_GYROSCOPE) && !defined(CALIBRATE_ACCELEROMETER) && !defined(CALIBRATE_MAGNETOMETER)
            if(takeCalibrationMeasurement()){
                text += doubleToString(writeMesurement.rot_x); text += "\t";
                text += doubleToString(writeMesurement.rot_y); text += "\t";
                text += doubleToString(writeMesurement.rot_z); text += "\n";
            }
            #else
            text += barPresent; text += ",";
            text += handPresent; text += ",";
            text += floatToString2Decimals(batteryVoltage); text += ",";

            text += String(setting_current_page); text += ",";
            text += floatToString2Decimals(getWeight(charToPage(setting_current_page))); text += ",";

            text += doubleToString(writeMesurement.lin_acc_x); text += ",";
            text += doubleToString(writeMesurement.lin_acc_y); text += ",";
            text += doubleToString(writeMesurement.lin_acc_z); text += ",";

            text += doubleToString(writeMesurement.abs_quat_w); text += ",";
            text += doubleToString(writeMesurement.abs_quat_x); text += ",";
            text += doubleToString(writeMesurement.abs_quat_y); text += ",";
            text += doubleToString(writeMesurement.abs_quat_z); text += ",";

            text += doubleToString(writeMesurement.acc_x); text += ",";
            text += doubleToString(writeMesurement.acc_y); text += ",";
            text += doubleToString(writeMesurement.acc_z); text += ",";
            
            text += doubleToString(writeMesurement.rot_x); text += ",";
            text += doubleToString(writeMesurement.rot_y); text += ",";
            text += doubleToString(writeMesurement.rot_z); text += ",";

            text += doubleToString(writeMesurement.temp); text += ",";
            
            text += doubleToString(writeMesurement.mag_x); text += ",";
            text += doubleToString(writeMesurement.mag_y); text += ",";
            text += doubleToString(writeMesurement.mag_z); text += ",";
            
            text += doubleToString(writeMesurement.abs_height); text += ",";
            
            text += writeMesurement.time_since_last_measure_us; text += "\n";
            #endif
        }
        stringDoneTime= esp_timer_get_time();
        if(!text.isEmpty()){
            logData(text);
        }
        taskDoneTime = esp_timer_get_time();


        /*Serial.print("Total time was: ");
        Serial.print(taskDoneTime-taskSDCardStartTime);
        Serial.print("\t| String creation took: ");
        Serial.print(stringDoneTime-taskSDCardStartTime);
        Serial.print("\t| Write to sd card took: ");
        Serial.print(taskDoneTime-stringDoneTime);
        Serial.print("us\t| Free Space was: ");
        Serial.print(freeSpace);
        Serial.print(" out of ");
        Serial.println(sensorReadingsQueueLen);*/
        
        
        xSemaphoreGive(spiControlMutex);
    }
}

void setup() {
    Serial.begin(115200);
    Serial.println("Setup start");


    Wire.begin(21, 22);         // SDA pin 21, SCL pin 22
    Wire.setClock(400000);      // Set I2C frequency to 400kHz
    Serial.println("Initialising I2C Master: sda=21 scl=22 freq=400000");
    
    setupPiezo();
    setupAnalogSensors();
    setupInputWheel();
    setupDisplay();
    delay(250);
    displayStartupScreen();
    delay(250);


    delay(50);
    bool sd_works = setupSDCard();
    displayStartupState(0, sd_works);
    delay(50);
    bool imc_works = setupICM42688P();
    displayStartupState(1, imc_works);
    delay(50);
    bool mmc_works = setupMMC5983MA();
    displayStartupState(2, mmc_works);
    delay(50);
    bool bmp_works = setupBMP390();
    displayStartupState(3, bmp_works);
    delay(50);
    bool bno_works = setupBNO055();
    displayStartupState(4, bno_works);
    delay(250);


    if(!sd_works || !imc_works|| !mmc_works|| !bmp_works|| !bno_works){
        delay(750);
        displayFailPage("Initializing failed!");
        return;
    }
    Wire.setClock(400000);      // Set I2C frequency to 400kHz


    uint8_t sys, gyro, accel, mag = 0;
    if(!bno055HasCalibrationSettingsStored()){
        bool isCal = bno055IsFullyCalibrate();
        while (!isCal){
            bno055GetCalibration(&sys, &gyro, &accel, &mag);
            displayBNO055CalibrationScreen(sys, gyro, accel, mag);
            isCal = bno055IsFullyCalibrate();
            delay(500);//~2fps
        }

        if(readBNO055OffsetsToSettings()){
            writeSettingsToSDCard();
        }else{
            displayFailPage("Write bno cal failed!");
            return;
        }
    } else {
        writeBNO055OffsetsFromSettings();
        delay(50);
        bno055GetCalibration(&sys, &gyro, &accel, &mag);
        displayBNO055CalibrationScreen(sys, gyro, accel, mag);
        delay(1000);//~2fps
    }


    displayBNO055CalibratedScreen();

    delay(1000);

    if(createNewDataLogFilePath() < 1 ){
        displayFailPage("Wrong file count!");
        return;
    }
    if(!createNewDataLogFile()){
        displayFailPage("Failed file create!");
    }

    displayStartingRecording();    
    
    semTimerReadSensors = xSemaphoreCreateBinary();
    spiControlMutex = xSemaphoreCreateMutex();

    sensorReadingsQueue = xQueueCreate(sensorReadingsQueueLen, sizeof(Measurement_t));

    // 520kByte total available
    xTaskCreatePinnedToCore(
                    taskHandleIO,
                    "taskHandleIO",
                    64*1024,//stack size bytes
                    NULL,
                    1,// Task priority (0 to configMAX_PRIORITIES - 1)
                    &taskHandleHandleIO,
                    core_sd_card_io);
    
     xTaskCreatePinnedToCore(
                    taskSDCard,
                    "taskSDCard",
                    40*1024,//stack size bytes
                    NULL,
                    2,// Task priority (0 to configMAX_PRIORITIES - 1)
                    &taskHandleSDCard,
                    core_sd_card_io);
    
    delayNonBlockingMillis(500);

    xTaskCreatePinnedToCore(
                    taskReadSensors,
                    "taskReadSensors",
                    8*1024,//stack size bytes
                    NULL, 
                    1,// Task priority (0 to configMAX_PRIORITIES - 1)
                    &taskHandleReadSensors,
                    core_sensors);
    
    Serial.println("Setup done");
}

void loop() {
    vTaskDelete(NULL);


    //testBMP390();
    
    //testBNO055();
    //testMMC5983MA();
    //testICM42688P();
    
    //test_logging();
    //serialPrintAnalogSensorTest();
    //serialPrintEncoderTest();
    //setPiezo(500,10000);
    //delay(1000);
    //testDisplay();
    //testBMP390();
    //tft.fillScreen(TFT_BLACK);
    //tft.setCursor(20, 4, 4);
    //tft.setTextColor(TFT_YELLOW);
    //tft.print("Voltage: ");
    //tft.print(readBatteryVoltage());
}

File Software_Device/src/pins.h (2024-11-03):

#pragma once

static const int BOOT_PIN            = 0;
static const int TX_PIN              = 1;
static const int RX_PIN              = 3;
static const int SDA_PIN             = 21;
static const int SCL_PIN             = 22;



static const int PIEZO               = 2;
static const int BUTTON_CENTER_S1    = 27;
static const int BUTTON_DOWN_S2      = 16;
static const int BUTTON_RIGHT_S3     = 4;
static const int BUTTON_UP_S4        = 25;
static const int BUTTON_LEFT_S5      = 26;
static const int ENCODER_A           = 17;
static const int ENCODER_B           = 13;



static const int VSPI_CLK            = 18;
static const int VSPI_MISO           = 19;
static const int VSPI_MOSI           = 23;

static const int DISPLAY_RES         = 12;
static const int DISPLAY_DC          = 14;
static const int DISPLAY_BL          = 33;
static const int VSPI_CS_DISPLAY     = 15;

static const int VSPI_CS_SD_CARD     = 5;



static const int MAG_INT             = 34;
static const int IMU_INT1            = 35;



static const int ANALOG_BAT_SENS     = 32;       
static const int ANALOG_BAR_SENS     = 36; //SENSOR_VP
static const int ANALOG_HAND_SENS    = 39; //SENSOR_VN

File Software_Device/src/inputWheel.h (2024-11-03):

#pragma once
#include <Arduino.h>
#include "piezo.h"
#include "pins.h"

volatile int button_center_presses = 0;
volatile int button_down_presses = 0;
volatile int button_right_presses = 0;
volatile int button_up_presses = 0;
volatile int button_left_presses = 0;

volatile int encoder = 0;

volatile int64_t debounceStart_us_CENTER = esp_timer_get_time();
volatile int64_t debounceStart_us_DOWN = esp_timer_get_time();
volatile int64_t debounceStart_us_RIGHT = esp_timer_get_time();
volatile int64_t debounceStart_us_UP = esp_timer_get_time();
volatile int64_t debounceStart_us_LEFT = esp_timer_get_time();
const int buttonDebounceTime_us = 200'000;


#if defined(CALIBRATE_ACCELEROMETER)
volatile int64_t lastPressTimeCenterButton_us = UINT64_MAX/2;//ensure inital value does not trigger calibration
const uint64_t buttonDelayTillCalibrationMeasurement_us = 1'500'000;//1.5sec
const uint64_t buttonCalibrationMeasurementTime_us = 200'000;//0.2sec
#elif defined(CALIBRATE_GYROSCOPE)
volatile int64_t lastPressTimeCenterButton_us = UINT64_MAX/2;//ensure inital value does not trigger calibration
const uint64_t buttonDelayTillCalibrationMeasurement_us = 30'000'000;//30sec
const uint64_t buttonCalibrationMeasurementTime_us = 120'000'000;//2min
#endif


void interruptButton_CENTER(){
    int64_t now = esp_timer_get_time();
    if(debounceStart_us_CENTER + buttonDebounceTime_us > now) {return;}
    debounceStart_us_CENTER = now;
    button_center_presses++;
    setPiezo(250,50);

    #if defined(CALIBRATE_ACCELEROMETER) || defined(CALIBRATE_GYROSCOPE)
    lastPressTimeCenterButton_us = esp_timer_get_time();
    #endif
}

#if defined(CALIBRATE_ACCELEROMETER) || defined(CALIBRATE_GYROSCOPE)
bool takeCalibrationMeasurement(){
    int64_t now = esp_timer_get_time();
    if(lastPressTimeCenterButton_us + buttonDelayTillCalibrationMeasurement_us > now) {return false;}
    if(lastPressTimeCenterButton_us + buttonDelayTillCalibrationMeasurement_us + buttonCalibrationMeasurementTime_us < now) {return false;}
    return true;
}
#endif


void interruptButton_DOWN(){
    int64_t now = esp_timer_get_time();
    if(debounceStart_us_DOWN + buttonDebounceTime_us > now) {return;}
    debounceStart_us_DOWN = now;
    button_down_presses++;
    //Serial.println("Down");
    setPiezo(250,50);
}
void interruptButton_RIGHT(){
    int64_t now = esp_timer_get_time();
    if(debounceStart_us_RIGHT + buttonDebounceTime_us > now) {return;}
    debounceStart_us_RIGHT = now;
    button_right_presses++;
    //Serial.println("Right");
    setPiezo(250,50);
}
void interruptButton_UP(){
    int64_t now = esp_timer_get_time();
    if(debounceStart_us_UP + buttonDebounceTime_us > now) {return;}
    debounceStart_us_UP = now;
    button_up_presses++;
    //Serial.println("Up");
    setPiezo(250,50);
}
void interruptButton_LEFT(){
    int64_t now = esp_timer_get_time();
    if(debounceStart_us_LEFT + buttonDebounceTime_us > now) {return;}
    debounceStart_us_LEFT = now;
    button_left_presses++;
    //Serial.println("Left");
    setPiezo(250,50);
}

void interruptEncoder_A(){
    int a = digitalRead(ENCODER_A);
    int b = digitalRead(ENCODER_B);
    if(a == HIGH && b == LOW || a == LOW && b == HIGH){
        encoder++;
    } else{//if(a == HIGH && b == HIGH || a == LOW && b == LOW)
        encoder--;
    }
    setPiezo(500,5);
}
void interruptEncoder_B(){
    int a = digitalRead(ENCODER_A);
    int b = digitalRead(ENCODER_B);
    if(a == HIGH && b == HIGH || a == LOW && b == LOW){
        encoder++;
    } else {//if(a == HIGH && b == LOW || a == LOW && b == HIGH)
        encoder--;
    }
    setPiezo(500,5);
}

void serialPrintEncoderTest(){
    Serial.print(encoder);
    Serial.println(" Encoder Value");
}

void setupInputWheel(){
    pinMode(BUTTON_CENTER_S1, INPUT);
    pinMode(BUTTON_DOWN_S2, INPUT);
    pinMode(BUTTON_RIGHT_S3, INPUT);
    pinMode(BUTTON_UP_S4, INPUT);
    pinMode(BUTTON_LEFT_S5, INPUT);
    pinMode(ENCODER_A, INPUT);
    pinMode(ENCODER_B, INPUT);
}

void attachInputWheelInterrupts(){ //call from core you want the interrupts to work on
    attachInterrupt(BUTTON_CENTER_S1, interruptButton_CENTER, FALLING);
    attachInterrupt(BUTTON_DOWN_S2, interruptButton_DOWN, FALLING);
    attachInterrupt(BUTTON_RIGHT_S3, interruptButton_RIGHT, FALLING);
    attachInterrupt(BUTTON_UP_S4, interruptButton_UP, FALLING);
    attachInterrupt(BUTTON_LEFT_S5, interruptButton_LEFT, FALLING);
    attachInterrupt(ENCODER_A, interruptEncoder_A, CHANGE);
    attachInterrupt(ENCODER_B, interruptEncoder_B, CHANGE);
}

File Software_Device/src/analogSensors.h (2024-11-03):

#pragma once
#include <Arduino.h>
#include "pins.h"

static const float voltage_divider = 55.1/33;
static const float voltage_offset = 0.2;

int barSensorValue = 4000;
int handSensorValue = 4000;

bool barPresent = false;
bool handPresent = true;
float batteryVoltage = 0;

void setupAnalogSensors(){
    pinMode(ANALOG_BAT_SENS, INPUT);
    pinMode(ANALOG_BAR_SENS, INPUT);
    pinMode(ANALOG_HAND_SENS, INPUT);
}

void updateBatteryVoltage(){
    float value = analogRead(ANALOG_BAT_SENS);
    batteryVoltage = value*3.3*voltage_divider/4095+voltage_offset;
}

int readBarSensor(){
    barSensorValue = barSensorValue*0.8+analogRead(ANALOG_BAR_SENS)*0.2;
    return barSensorValue;
}

int readHandSensor(){
    handSensorValue = handSensorValue*0.8+analogRead(ANALOG_HAND_SENS)*0.2;
    return handSensorValue;
}

void updateBarPresent(){
    readBarSensor();
    barPresent = barSensorValue<500;
}
void updateHandPresent(){
    readHandSensor();
    handPresent = handSensorValue<500;
}

void serialPrintAnalogSensorTest(){
    Serial.print("BatteryVoltage: ");
    updateBatteryVoltage();
    Serial.print(batteryVoltage);
    Serial.print("V");
    Serial.print("\tHandSensor: ");
    Serial.print(readHandSensor());
    Serial.print("\tBarSensor: ");
    Serial.println(readBarSensor());
    delay(20);
}
